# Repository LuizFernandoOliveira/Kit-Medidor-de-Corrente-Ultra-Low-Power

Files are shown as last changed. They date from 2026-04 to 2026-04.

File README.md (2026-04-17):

# Kit Medidor de Corrente Ultra-Low Power




## Descrição
Contendo quatro circuitos independentes de quatro topologias distintas, este circuito eletrônico é ideal para realizar a medição de corrente elétrica de diversas aplicação ultra-low power.

<p align="center">
  Imagem5
</p>

---

## Descrições técnicas

- Possui quatro circuitos independentes de corrente via transimpedância;
- Possui quatro circuitos independentes de corrente via rede T;
- Possui quatro circuitos independentes de corrente via High-Side;
- Possui quatro circuitos independentes de corrente via Low-Side;
- Possui alimentação de 3V3 ou 5V;
- Possui alimentação via USB tipo-C;
- Altíssima precisão e estabilidade: tensão de offset de 5 µV máx. a 25 °C, 8 µV em toda a faixa de temperatura (-40 °C a 125 °C);
- Entrada e saída rail-to-rail;
- Baixa tensão de alimentação: 1,8 - 5,5 V;
- Baixo consumo de energia: 40 µA máx. a 5 V;
- Produto ganho-largura de banda: 400 kHz;
- Alta tolerância a ESD: 4 kV HBM;
- Ampla faixa de temperatura de operação: -40 a 125 °C

---

## Estrutura do repositório
Os arquivos de hardware foram desenvolvidos utilizando o KiCad 9.0.
- **`.kicad_pcb`**: Layout da placa de circuito impresso (Board).
- **`.kicad_sch`**: Esquemático eletrônico do sistema (Schematic).
- **`.kicad_pro`**: Gerenciador de projeto do KiCad (Project).

---

## Autor
**Dr. Luiz Fernando Pinto de Oliveira**

*Engenheiro Eletrônico especializado em Sistemas Embarcados e Ultra-Low Power.*
- **Website:** [FAPLO](https://faplo.webnode.page/)
- **LinkedIn:** [lfpo](https://www.linkedin.com/in/lfpo/)

---

Shield: [][cc-by-nc-nd]

This work is licensed under a
[Creative Commons Attribution-NonCommercial-NoDerivs 4.0 International License][cc-by-nc-nd].

[][cc-by-nc-nd]

[cc-by-nc-nd]: http://creativecommons.org/licenses/by-nc-nd/4.0/
[cc-by-nc-nd-image]: https://licensebuttons.net/l/by-nc-nd/4.0/88x31.png
[cc-by-nc-nd-shield]: https://img.shields.io/badge/License-CC%20BY--NC--ND%204.0-lightgrey.svg

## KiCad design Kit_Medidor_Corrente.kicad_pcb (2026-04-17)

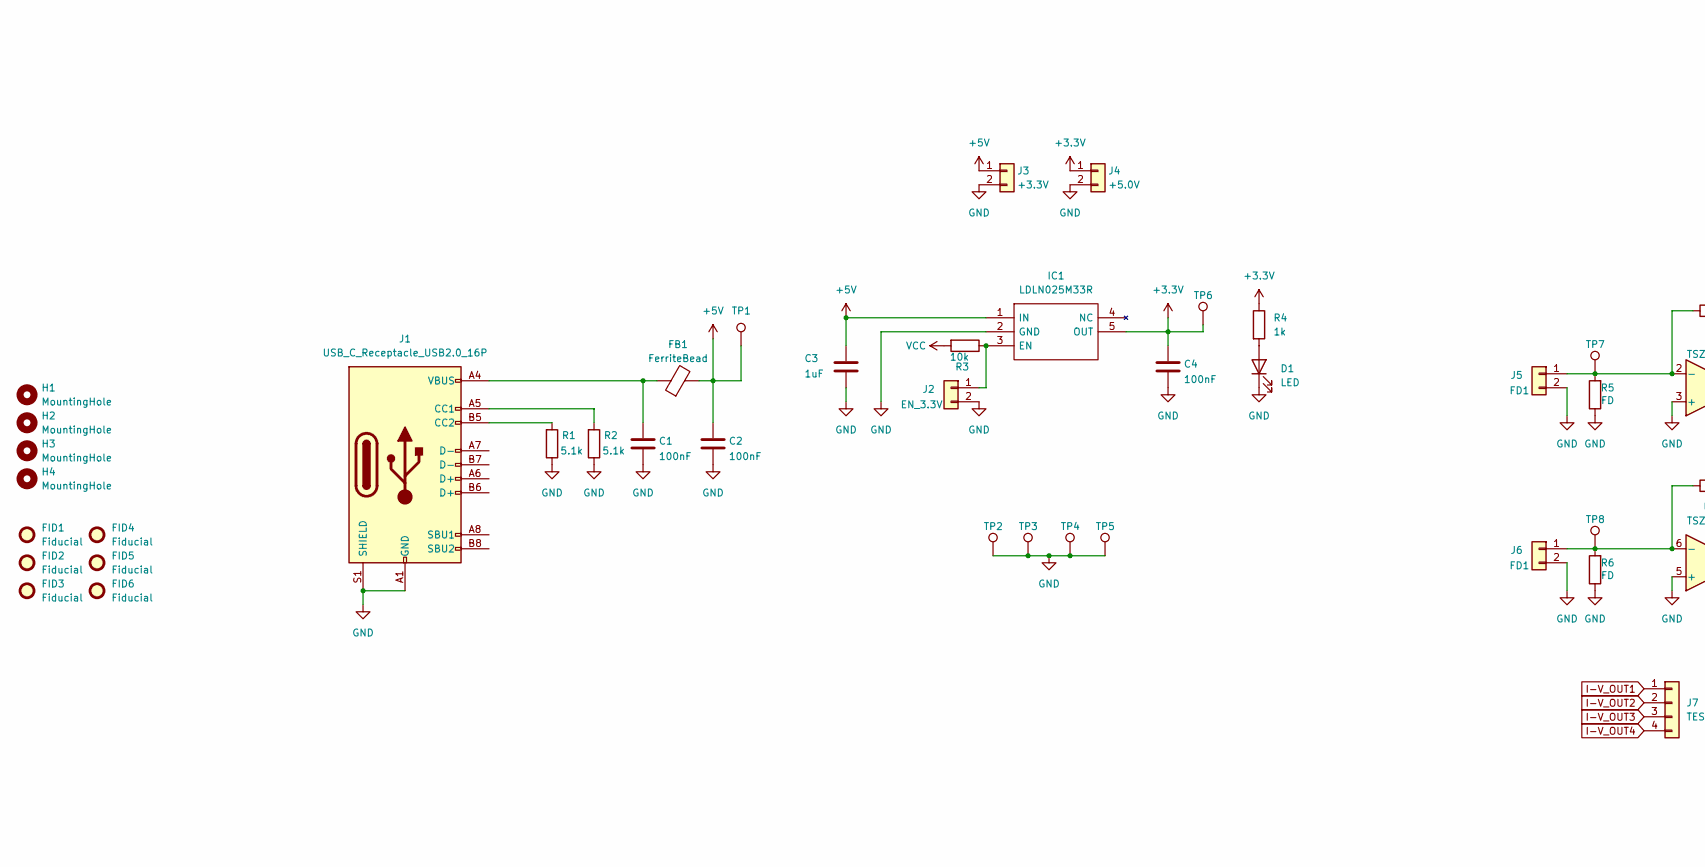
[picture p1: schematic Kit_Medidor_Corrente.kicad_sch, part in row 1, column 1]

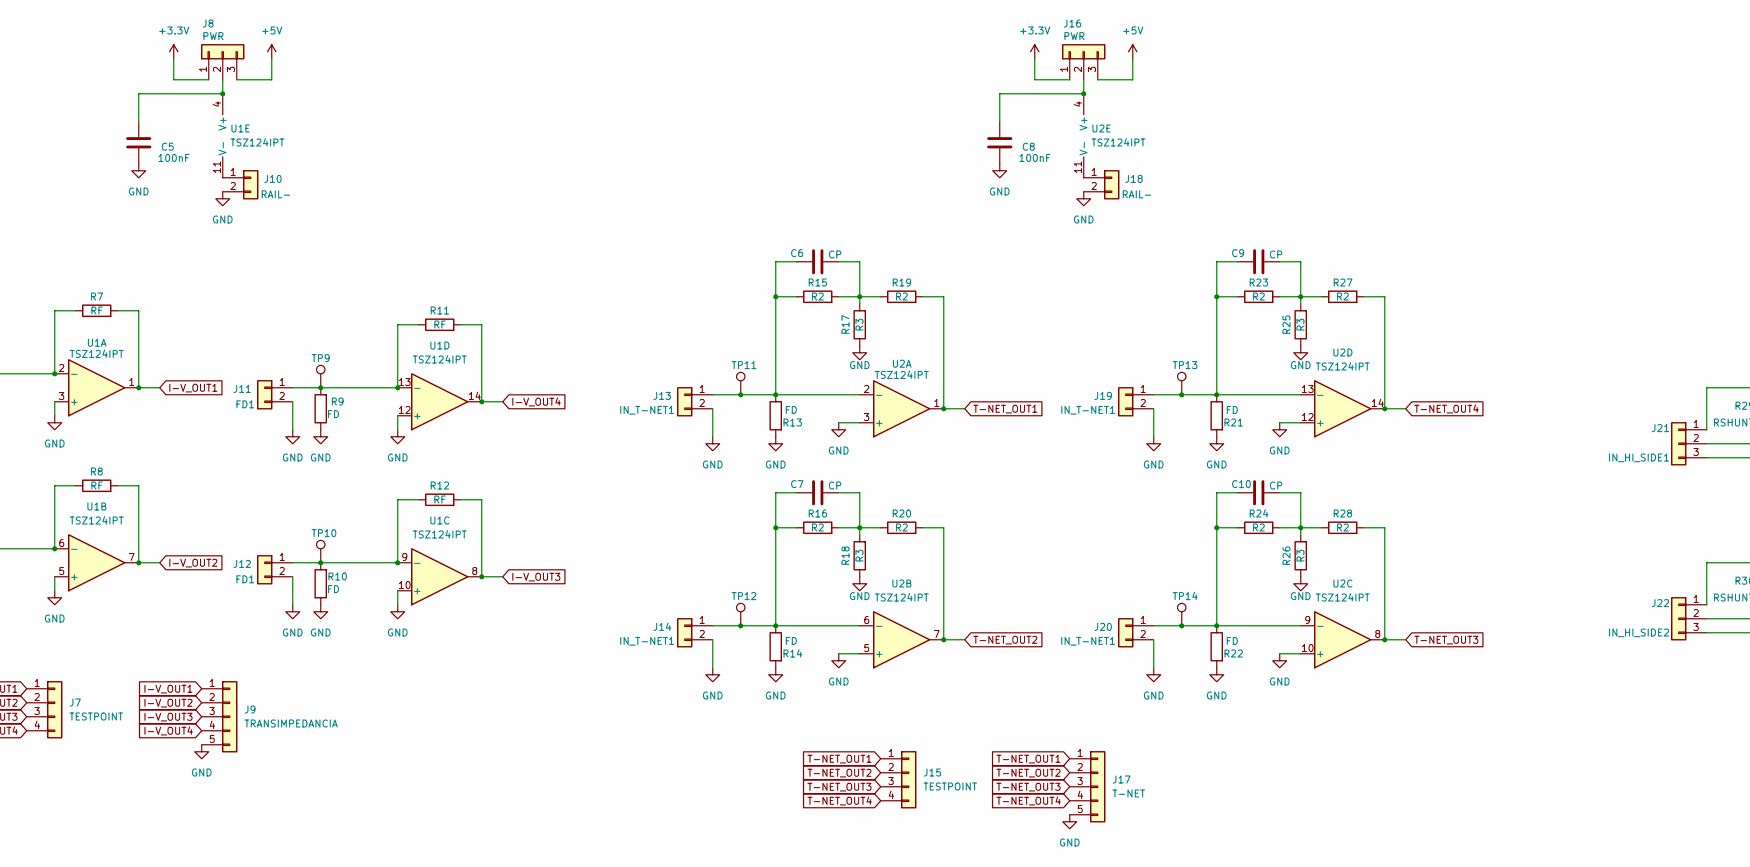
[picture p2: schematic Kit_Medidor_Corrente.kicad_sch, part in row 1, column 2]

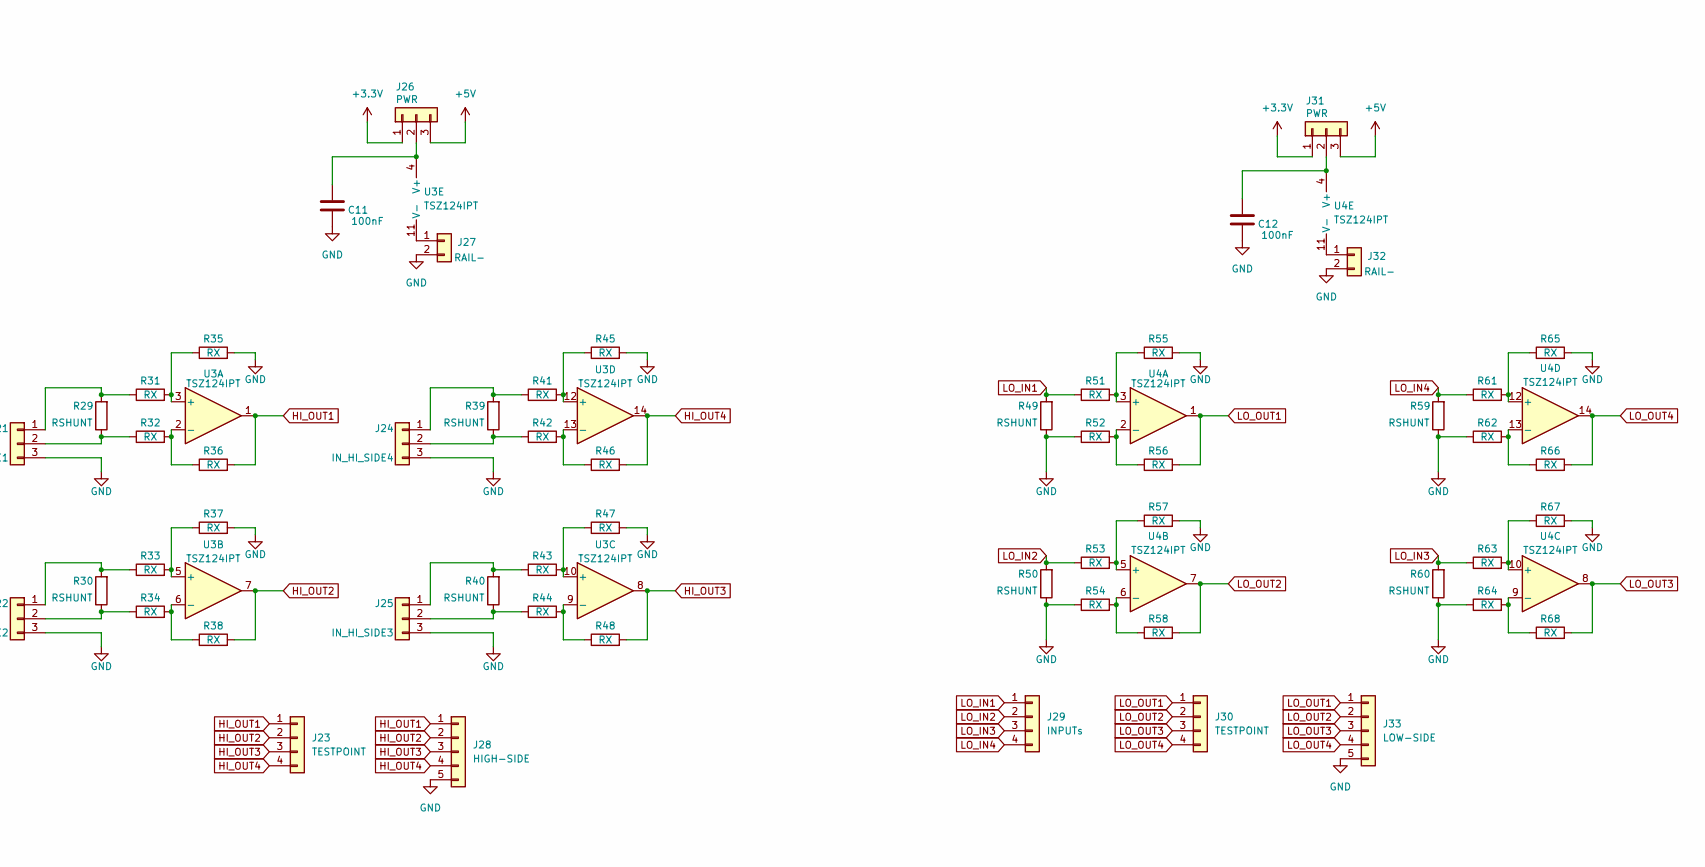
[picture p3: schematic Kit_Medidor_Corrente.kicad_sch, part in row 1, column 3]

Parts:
C1, C2, C4, C5, C8, C11, C12: 100nF; C_0805_2012Metric
C3: 1uF; C_0805_2012Metric
C6, C7, C9, C10: CP; C_0805_2012Metric
D1: LED; LED_0805_2012Metric
FB1: FerriteBead; L_0805_2012Metric
FID1, FID2, FID3, FID4, FID5, FID6: Fiducial; Fiducial_1mm_Mask2mm
H1, H2, H3, H4: MountingHole; MountingHole_3.2mm_M3_DIN965
IC1: LDLN025M33R; SOT95P280X145-5N; Manufacturer_Part_Number LDLN025M33R; Mouser Part Number 511-LDLN025M33R
J1: USB_C_Receptacle_USB2.0_16P; USB_C_Receptacle_HRO_TYPE-C-31-M-12
J2: EN_3.3V; PinHeader_1x02_P2.54mm_Vertical
J3: +3.3V; PinHeader_1x02_P2.54mm_Vertical
J4: +5.0V; PinHeader_1x02_P2.54mm_Vertical
J5, J6, J11, J12: FD1; PinHeader_1x02_P2.54mm_Vertical
J7, J15, J23, J30: TESTPOINT; PinHeader_1x04_P2.54mm_Vertical
J8, J16, J26, J31: PWR; PinHeader_1x03_P2.54mm_Vertical
J9: TRANSIMPEDANCIA; PinHeader_1x05_P2.54mm_Vertical
J10, J18, J27, J32: RAIL-; PinHeader_1x02_P2.54mm_Vertical
J13, J14, J19, J20: IN_T-NET1; PinHeader_1x02_P2.54mm_Vertical
J17: T-NET; PinHeader_1x05_P2.54mm_Vertical
J21: IN_HI_SIDE1; PinHeader_1x03_P2.54mm_Vertical
J22: IN_HI_SIDE2; PinHeader_1x03_P2.54mm_Vertical
J24: IN_HI_SIDE4; PinHeader_1x03_P2.54mm_Vertical
J25: IN_HI_SIDE3; PinHeader_1x03_P2.54mm_Vertical
J28: HIGH-SIDE; PinHeader_1x05_P2.54mm_Vertical
J29: INPUTs; PinHeader_1x04_P2.54mm_Vertical
J33: LOW-SIDE; PinHeader_1x05_P2.54mm_Vertical
R1, R2: 5.1k; R_0805_2012Metric
R3: 10k; R_0805_2012Metric
R4: 1k; R_0805_2012Metric
R5, R6, R9, R10, R13, R14, R21, R22: FD; R_0805_2012Metric
R7, R8, R11, R12: RF; R_0805_2012Metric
R15, R16, R19, R20, R23, R24, R27, R28: R2; R_0805_2012Metric
R17, R18, R25, R26: R3; R_0805_2012Metric
R29, R30, R39, R40, R49, R50, R59, R60: RSHUNT; R_0805_2012Metric
R31, R32, R33, R34, R35, R36, R37, R38, R41, R42, R43, R44, R45, R46, R47, R48, R51, R52, R53, R54, R55, R56, R57, R58, R61, R62, R63, R64, R65, R66, R67, R68: RX; R_0805_2012Metric
TP1, TP2, TP3, TP4, TP5, TP6, TP7, TP8, TP9, TP10, TP11, TP12, TP13, TP14: TestPoint; TestPoint_Loop_D1.80mm_Drill1.0mm_Beaded
U1, U2, U3, U4: TSZ124IPT; SOP65P640X120-14N

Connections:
+3.3V: C4.1, IC1.5 (OUT), J4.1, J8.1, J16.1, J26.1, J31.1, R4.1, TP6.1
+5V: C2.1, C3.1, FB1.2, IC1.1 (IN), J3.1, J8.3, J16.3, J26.3, J31.3, TP1.1
GND: C1.2, C2.2, C3.2, C4.2, C5.1, C8.1, C11.1, C12.1, D1.1 (K), IC1.2 (GND), J1.A1 (GND), J1.A12 (GND), J1.B1 (GND), J1.B12 (GND), J1.S1 (SHIELD), J2.2, J3.2, J4.2, J5.2, J6.2, J9.5, J10.2, J11.2, J12.2, J13.2, J14.2, J17.5, J18.2, J19.2, J20.2, J21.3, J22.3, J24.3, J25.3, J27.2, J28.5, J32.2, J33.5, R1.1, R2.1, R5.1, R6.1, R9.1, R10.1, R13.2, R14.2, R17.1, R18.1, R21.2, R22.2, R25.1, R26.1, R35.2, R37.2, R45.2, R47.2, R49.1, R50.1, R52.1, R54.1, R55.2, R57.2, R59.1, R60.1, R62.1, R64.1, R65.2, R67.2, TP2.1, TP3.1, TP4.1, TP5.1, U1.3 (+), U1.5 (+), U1.10 (+), U1.12 (+), U2.3 (+), U2.5 (+), U2.10 (+), U2.12 (+)
HI_OUT1: J23.1, J28.1, R36.2, U3.1
HI_OUT2: J23.2, J28.2, R38.2, U3.7
HI_OUT3: J23.3, J28.3, R48.2, U3.8
HI_OUT4: J23.4, J28.4, R46.2, U3.14
I-V_OUT1: J7.1, J9.1, R7.2, U1.1
I-V_OUT2: J7.2, J9.2, R8.2, U1.7
I-V_OUT3: J7.3, J9.3, R12.2, U1.8
I-V_OUT4: J7.4, J9.4, R11.2, U1.14
LO_IN1: J29.1, R49.2, R51.1
LO_IN2: J29.2, R50.2, R53.1
LO_IN3: J29.3, R60.2, R63.1
LO_IN4: J29.4, R59.2, R61.1
LO_OUT1: J30.1, J33.1, R56.2, U4.1
LO_OUT2: J30.2, J33.2, R58.2, U4.7
LO_OUT3: J30.3, J33.3, R68.2, U4.8
LO_OUT4: J30.4, J33.4, R66.2, U4.14
unnamed: C1.1, FB1.1, J1.A4 (VBUS), J1.A9 (VBUS), J1.B4 (VBUS), J1.B9 (VBUS)
unnamed: C6.1, R15.2, R17.2, R19.1
unnamed: C7.1, R16.2, R18.2, R20.1
unnamed: C9.1, R23.2, R25.2, R27.1
unnamed: C10.1, R24.2, R26.2, R28.1
unnamed: D1.2 (A), R4.2
unnamed: IC1.3 (EN), J2.1, R3.1
unnamed: J1.A5 (CC1), R2.2
unnamed: J1.B5 (CC2), R1.2
unnamed: J5.1, R5.2, R7.1, TP7.1, U1.2 (-)
unnamed: J6.1, R6.2, R8.1, TP8.1, U1.6 (-)
unnamed: C5.2, J8.2, U1.4 (V+)
unnamed: J10.1, U1.11 (V-)
unnamed: J11.1, R9.2, R11.1, TP9.1, U1.13 (-)
unnamed: J12.1, R10.2, R12.1, TP10.1, U1.9 (-)
unnamed: C6.2, J13.1, R13.1, R15.1, TP11.1, U2.2 (-)
unnamed: C7.2, J14.1, R14.1, R16.1, TP12.1, U2.6 (-)
unnamed: C8.2, J16.2, U2.4 (V+)
unnamed: J18.1, U2.11 (V-)
unnamed: C9.2, J19.1, R21.1, R23.1, TP13.1, U2.13 (-)
unnamed: C10.2, J20.1, R22.1, R24.1, TP14.1, U2.9 (-)
unnamed: J21.1, R29.2, R31.1
unnamed: J21.2, R29.1, R32.1
unnamed: J22.1, R30.2, R33.1
unnamed: J22.2, R30.1, R34.1
unnamed: J24.1, R39.2, R41.1
unnamed: J24.2, R39.1, R42.1
unnamed: J25.1, R40.2, R43.1
unnamed: J25.2, R40.1, R44.1
unnamed: C11.2, J26.2, U3.4 (V+)
unnamed: J27.1, U3.11 (V-)
unnamed: C12.2, J31.2, U4.4 (V+)
unnamed: J32.1, U4.11 (V-)
unnamed: R31.2, R35.1, U3.3 (+)
unnamed: R32.2, R36.1, U3.2 (-)
unnamed: R33.2, R37.1, U3.5 (+)
unnamed: R34.2, R38.1, U3.6 (-)
unnamed: R43.2, R47.1, U3.10 (+)
unnamed: R44.2, R48.1, U3.9 (-)
unnamed: R41.2, R45.1, U3.12 (+)
unnamed: R42.2, R46.1, U3.13 (-)
unnamed: R51.2, R55.1, U4.3 (+)
unnamed: R52.2, R56.1, U4.2 (-)
unnamed: R53.2, R57.1, U4.5 (+)
unnamed: R54.2, R58.1, U4.6 (-)
unnamed: R63.2, R67.1, U4.10 (+)
unnamed: R64.2, R68.1, U4.9 (-)
unnamed: R61.2, R65.1, U4.12 (+)
unnamed: R62.2, R66.1, U4.13 (-)
T-NET_OUT1: J15.1, J17.1, R19.2, U2.1
T-NET_OUT2: J15.2, J17.2, R20.2, U2.7
T-NET_OUT3: J15.3, J17.3, R28.2, U2.8
T-NET_OUT4: J15.4, J17.4, R27.2, U2.14
VCC: R3.2

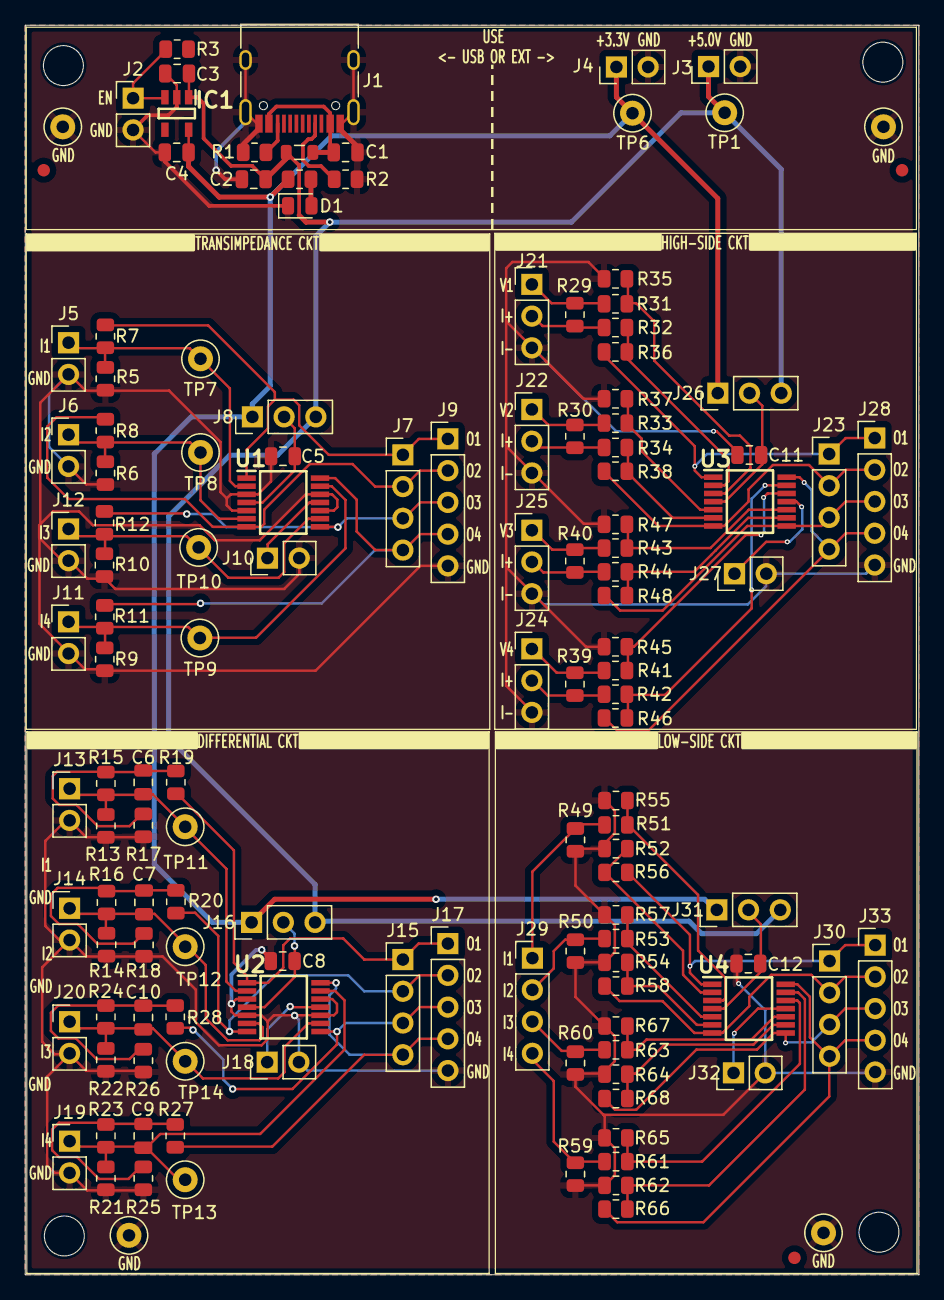
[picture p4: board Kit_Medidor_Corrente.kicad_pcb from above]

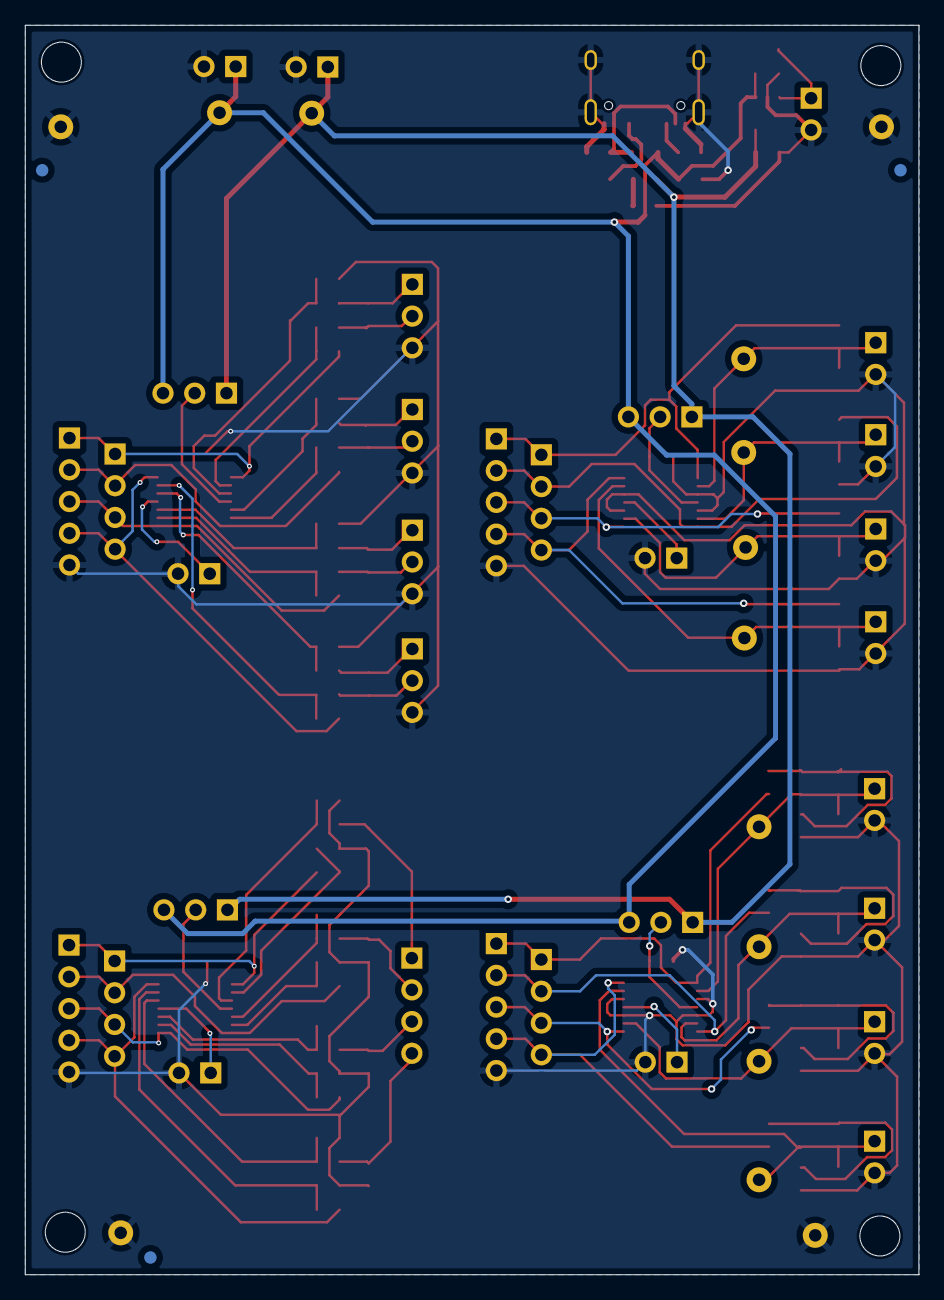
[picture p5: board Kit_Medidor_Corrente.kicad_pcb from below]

Board: 2 copper layers, 71.5 x 100.0 mm, 144 parts (3 on the bottom side), 72 nets.

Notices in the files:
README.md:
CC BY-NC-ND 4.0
